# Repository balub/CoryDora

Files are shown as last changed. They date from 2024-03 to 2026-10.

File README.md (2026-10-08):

# CoryDora

A simple open-source, RP2040-based, QMK-compatible 3x3 mechanical macropad.

## Rationale

The main goal of this project is to have a cheap, easy-to-build, feature-rich numpad which is completely open source.

You can now buy the CoryDora yourself at the [Absurd Store](https://shop.absurd.industries/products/cory-dora).
Onboarding instructions are available [here](https://rowan-ninja-baa.notion.site/CoryDora-Onboarding-12d9d3177a9b8016bcddd6904b028f71).
Full build guide is available [here](https://rowan-ninja-baa.notion.site/CoryDora-v1-1-Build-Guide-cc727f8be312492a9d3bb8e5530b1656).

<p align="center">
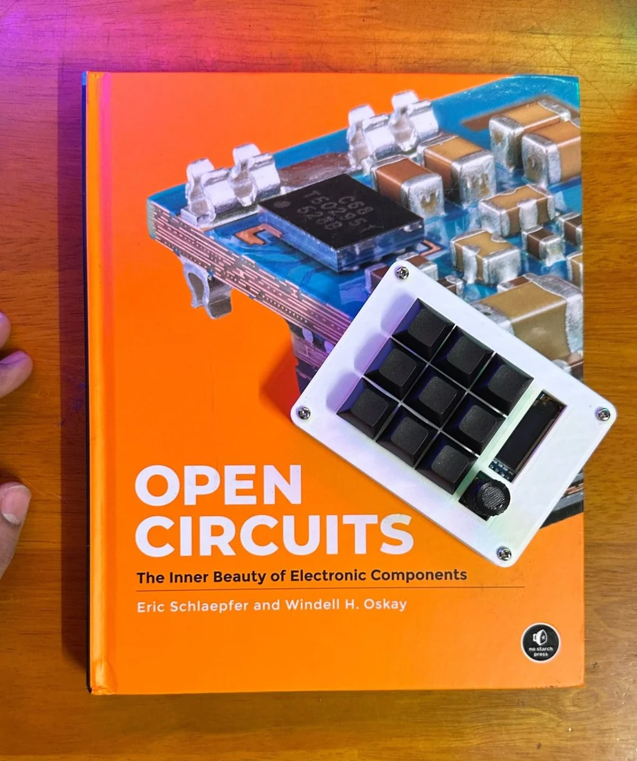
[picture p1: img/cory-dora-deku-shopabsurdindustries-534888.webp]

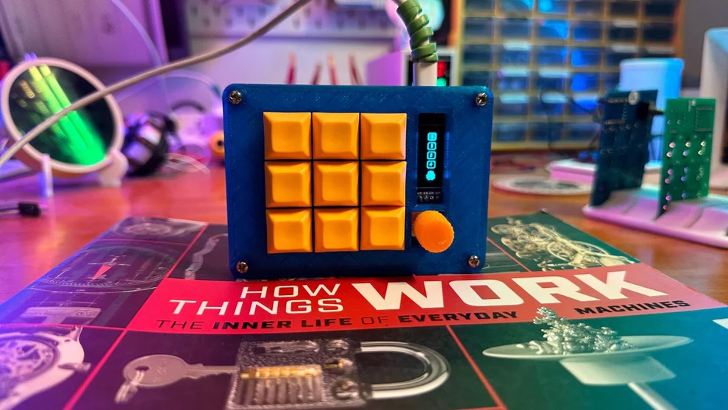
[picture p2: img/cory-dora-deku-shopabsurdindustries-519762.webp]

</p>

## Features:

- Easy to source and build components.
- Hot swappable keys.
- QMK compatible.
- OLED 0.91" screen.
- At least 1 rotary encoder
- Completely open-source.

## Parts list
**Part**|**Quantity**|**Link to buy online**
:-----:|:-----:|:-----:
 Hotswap Sockets|9|https://stackskb.com/store/ttc-pokayoke-hotswap-sockets-v2-10000-cycles
 Through hole 1N4148 Diode|9|https://stackskb.com/store/1n4148-through-hole-diode
 RP2040 zero|1|https://robu.in/product/waveshare-rp2040-zero-without-header
 Rotary Encoders|1|https://robu.in/product/m274-360-degree-rotary-encoder-module-brick-sensor/
 0.91 inch I2C OLED display|1|https://robu.in/product/0-91-inch-128x32-i2c-iic-serial-oled-lcd-display-modulewith-gn
 Mx compatible mechanical switches|9|https://stackskb.com/product-category/switches/linear/

## Firmware

Clone [forked QMK](https://github.com/balub/qmk_firmware) repositories and set up the build environment. See the [build environment setup](https://docs.qmk.fm/#/getting_started_build_tools) and the [make instructions](https://docs.qmk.fm/#/getting_started_make_guide) for more information. Brand new to QMK? Start with our [Complete Newbs Guide](https://docs.qmk.fm/#/newbs).

QMK


## License

Original CoryDora hardware designs and accompanying documentation are licensed
under **CERN-OHL-S-2.0**. You may use, modify, manufacture, and sell the hardware
under its terms. Retain the project attribution and other applicable notices;
provide the complete editable sources under the same licence when required
for distributed derivatives.

See [licensing scope and third-party exclusions](LICENSE) and the
[complete licence text](LICENSES/CERN-OHL-S-2.0.txt). Third-party material retains
its existing licences. The [separate QMK firmware fork](https://github.com/balub/qmk_firmware)
retains its applicable upstream and file-specific licences.

Attribution: **CoryDora project and its contributors**.
Source location: <https://github.com/balub/CoryDora>.

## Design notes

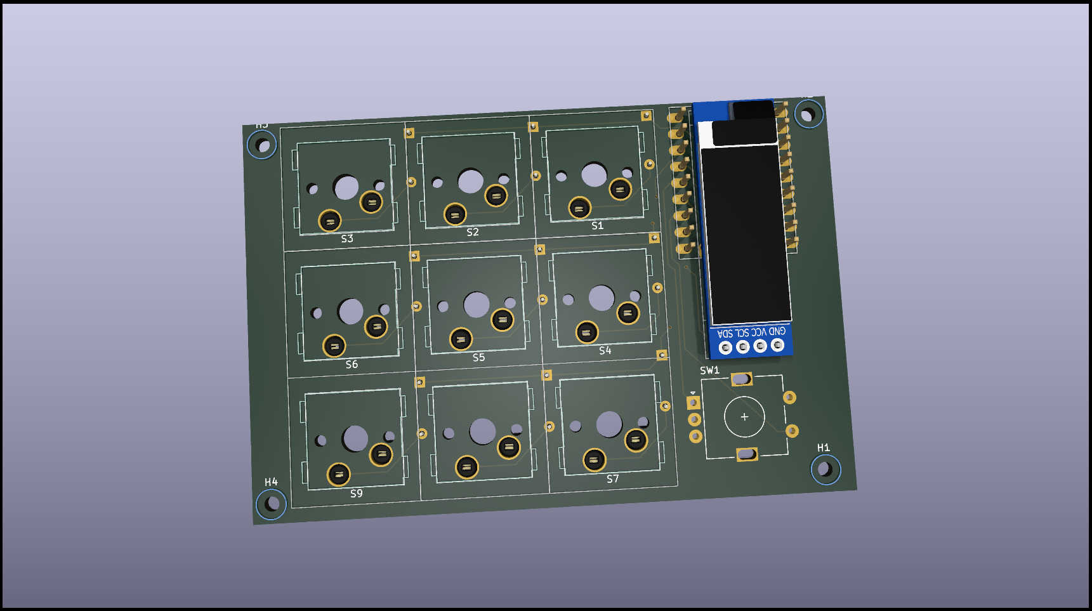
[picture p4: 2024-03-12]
img/CoryDora-front.png

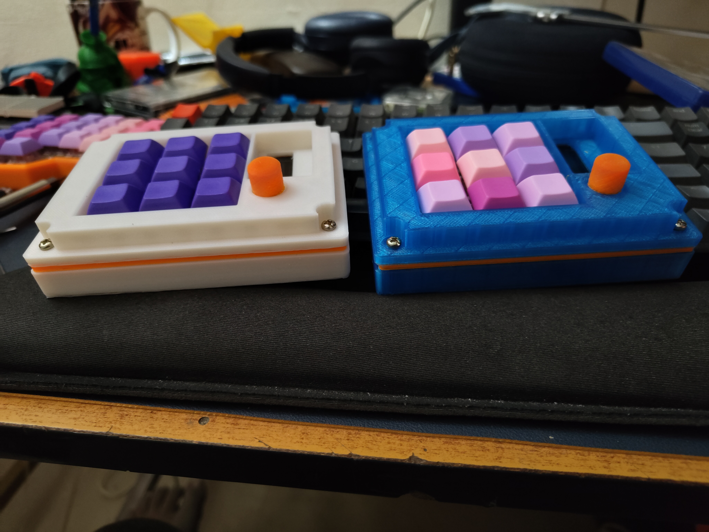
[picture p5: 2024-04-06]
img/CoryDora_Real.jpg

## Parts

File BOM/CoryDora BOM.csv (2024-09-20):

Reference | Value | Datasheet | Footprint | Qty | DNP
D1,D2,D3,D4,D5,D6,D7,D8,D9 | Diode |  | ScottoKeebs_Components:Diode_DO-35 | 9
H1,H2,H3,H4 | MountingHole | ~ | MountingHole:MountingHole_2.2mm_M2 | 4
J1 | OLED_128x32 |  | ScottoKeebs_Components:OLED_128x32 | 1
S1,S2,S3,S4,S5,S6,S7,S8,S9 | Keyswitch | ~ | ScottoKeebs_Hotswap:Hotswap_MX_Plated_1.00u | 9
SW1 | RotaryEncoder_Switch | ~ | Rotary_Encoder:RotaryEncoder_Alps_EC11E-Switch_Vertical_H20mm | 1
U1 | RP2040_Zero |  | ScottoKeebs_MCU:RP2040_Zero | 1

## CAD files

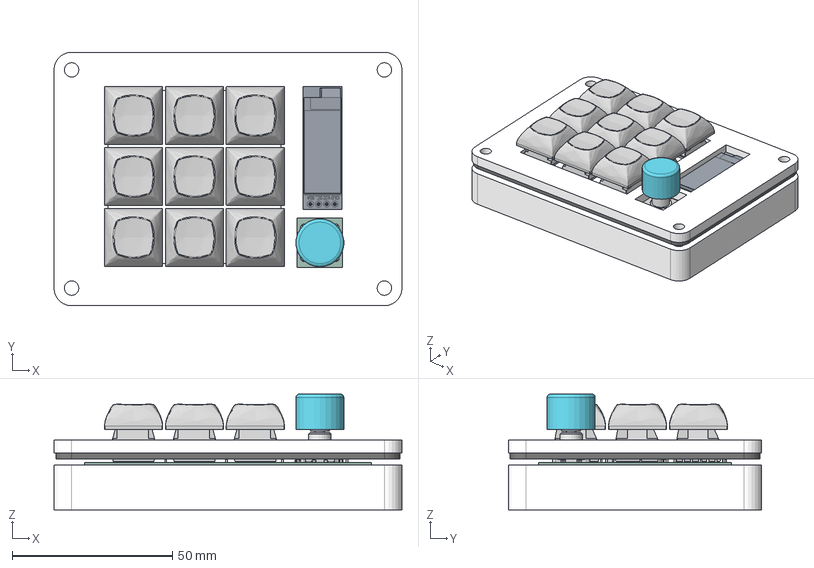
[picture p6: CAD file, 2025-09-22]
Case/v1.2/CoryDora_Fully_Assembled_v1.2.step
108.6 x 79.1 x 36.2 mm
switch v1_9 x 9
EC11
OLED_0.91_128x32
D_DO-35_SOD27_P7.62mm_Horizontal x 9
root
CoryDora_PCB
Case_Bottom
Case_trim
Case_top
Knob
MX Mount v1 x 9

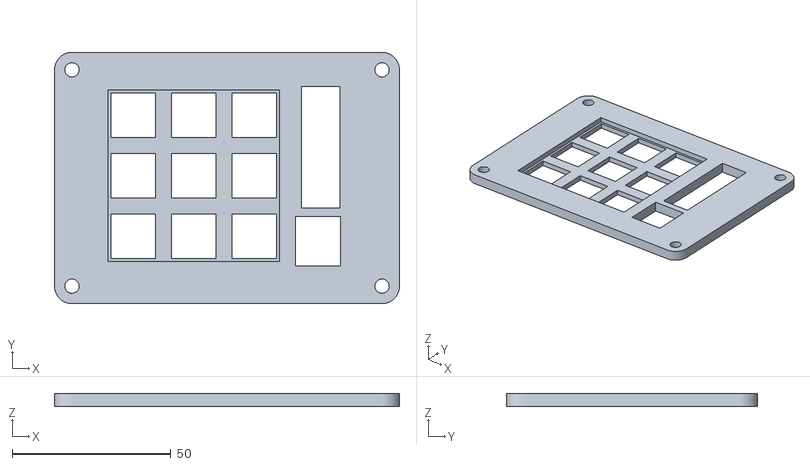
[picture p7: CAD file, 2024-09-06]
Case/v1.2/STLs/Case_top.stl
108.6 x 79.1 x 4.07

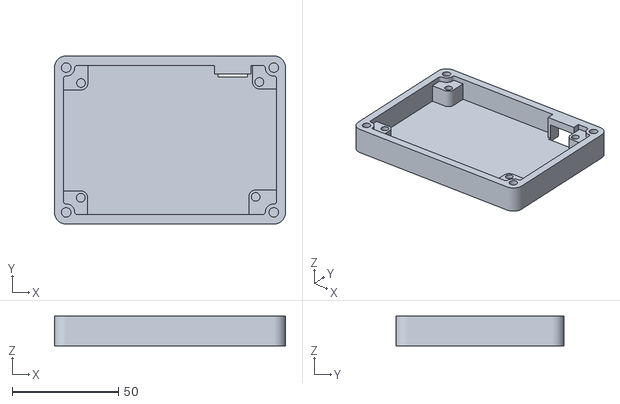
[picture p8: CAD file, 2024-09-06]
Case/v1.2/STLs/Case_Bottom.stl
108.6 x 79.1 x 14.0

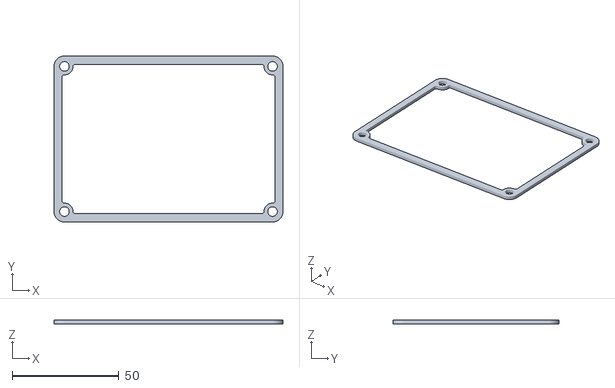
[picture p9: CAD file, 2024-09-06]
Case/v1.2/STLs/Case_trim.stl
107.4 x 77.9 x 1.80

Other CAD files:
Case/v1.2/CoryDora_Fully_Assembled_v1.2.f3z

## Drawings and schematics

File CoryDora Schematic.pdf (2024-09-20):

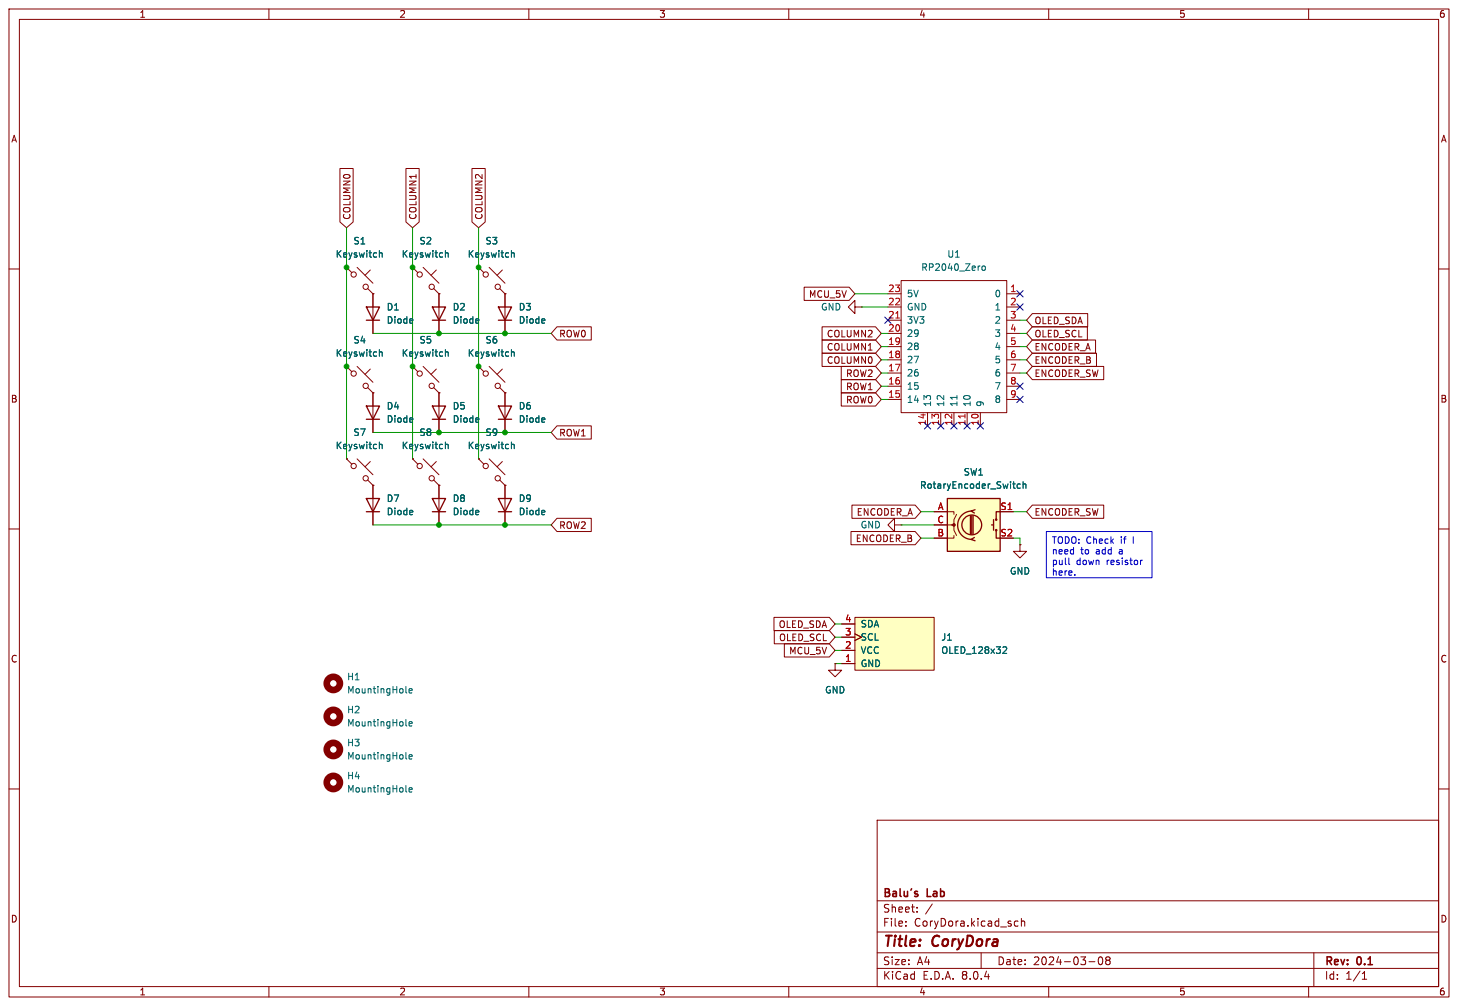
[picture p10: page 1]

TODO: Check if I need to add a

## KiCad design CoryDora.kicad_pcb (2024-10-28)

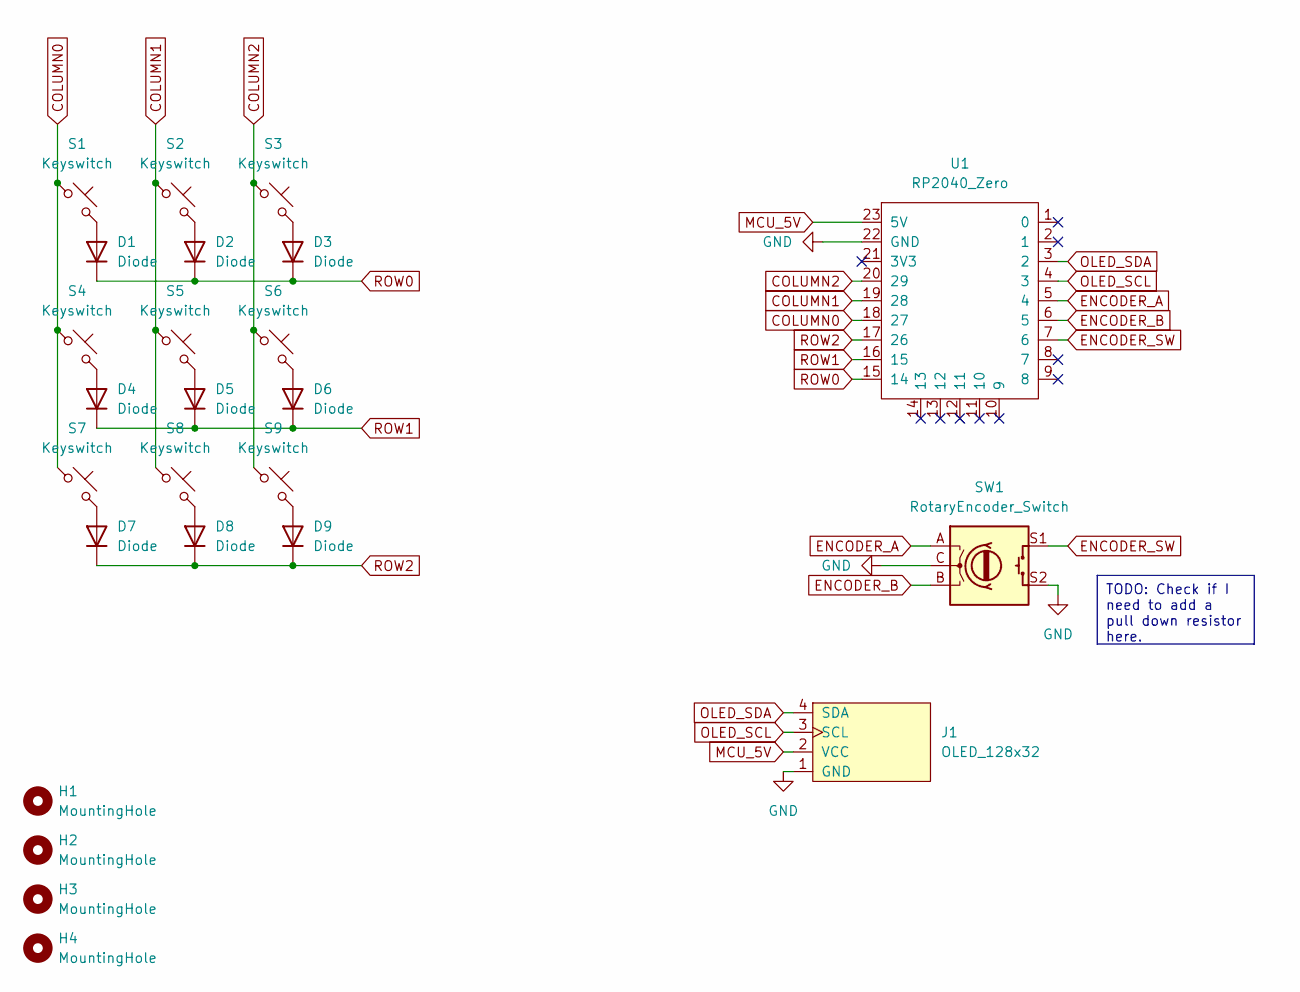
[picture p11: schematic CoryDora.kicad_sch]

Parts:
D1, D2, D3, D4, D5, D6, D7, D8, D9: Diode; Diode_DO-35
H1, H2, H3, H4: MountingHole; MountingHole_2.2mm_M2
J1: OLED_128x32
S1, S2, S3, S4, S5, S6, S7, S8, S9: Keyswitch; Hotswap_MX_Plated_1.00u
SW1: RotaryEncoder_Switch; RotaryEncoder_Alps_EC11E-Switch_Vertical_H20mm
U1: RP2040_Zero

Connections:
COLUMN0: S1.1, S4.1, S7.1, U1.18 (27)
COLUMN1: S2.1, S5.1, S8.1, U1.19 (28)
COLUMN2: S3.1, S6.1, S9.1, U1.20 (29)
ENCODER_A: SW1.A, U1.5 (4)
ENCODER_B: SW1.B, U1.6 (5)
ENCODER_SW: SW1.S1, U1.7 (6)
GND: J1.1 (GND), SW1.C, SW1.S2, U1.22 (GND)
MCU_5V: J1.2 (VCC), U1.23 (5V)
unnamed: D1.2 (A), S1.2
unnamed: D2.2 (A), S2.2
unnamed: D3.2 (A), S3.2
unnamed: D4.2 (A), S4.2
unnamed: D5.2 (A), S5.2
unnamed: D6.2 (A), S6.2
unnamed: D7.2 (A), S7.2
unnamed: D8.2 (A), S8.2
unnamed: D9.2 (A), S9.2
OLED_SCL: J1.3 (SCL), U1.4 (3)
OLED_SDA: J1.4 (SDA), U1.3 (2)
ROW0: D1.1 (K), D2.1 (K), D3.1 (K), U1.15 (14)
ROW1: D4.1 (K), D5.1 (K), D6.1 (K), U1.16 (15)
ROW2: D7.1 (K), D8.1 (K), D9.1 (K), U1.17 (26)

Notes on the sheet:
TODO: Check if I need to add a pull down resistor here.

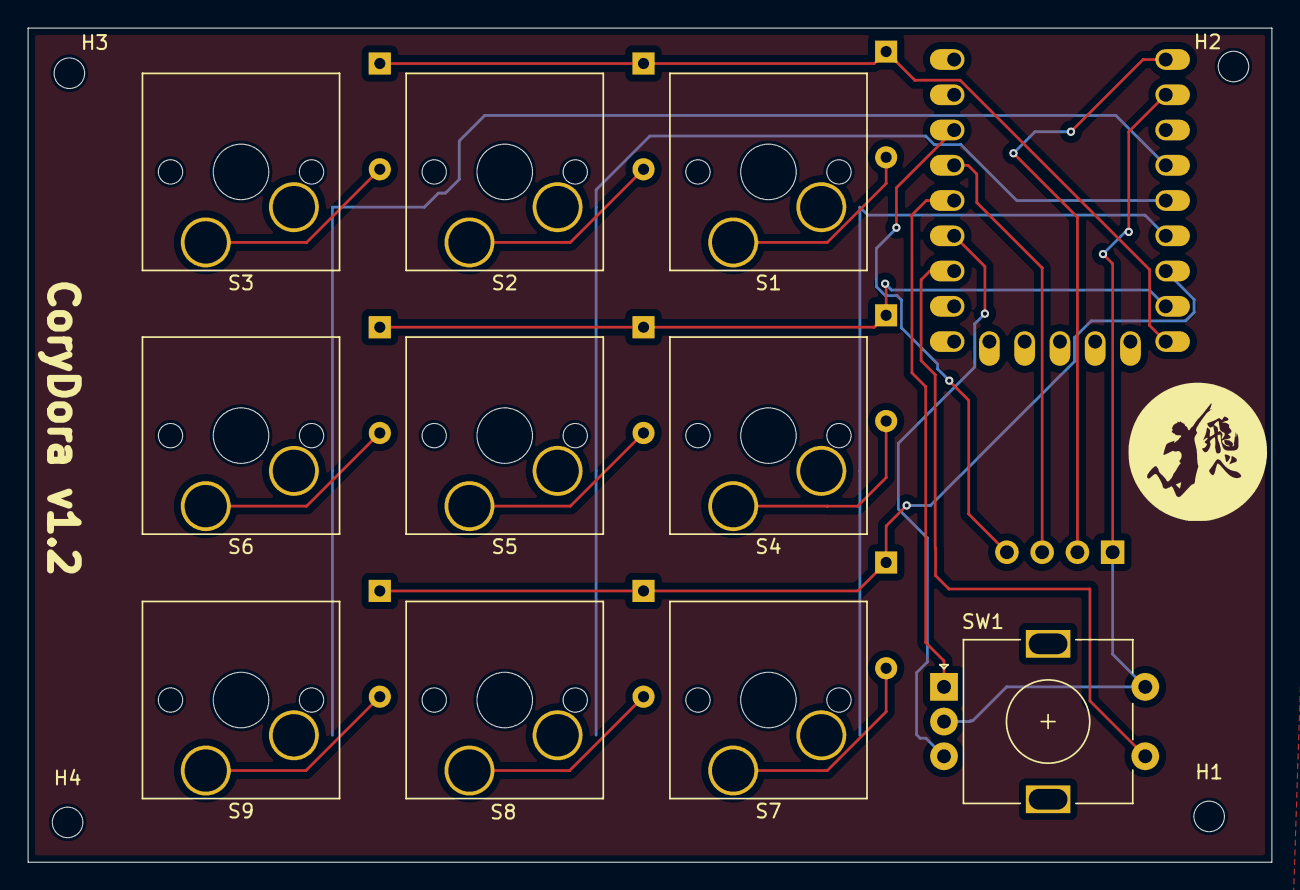
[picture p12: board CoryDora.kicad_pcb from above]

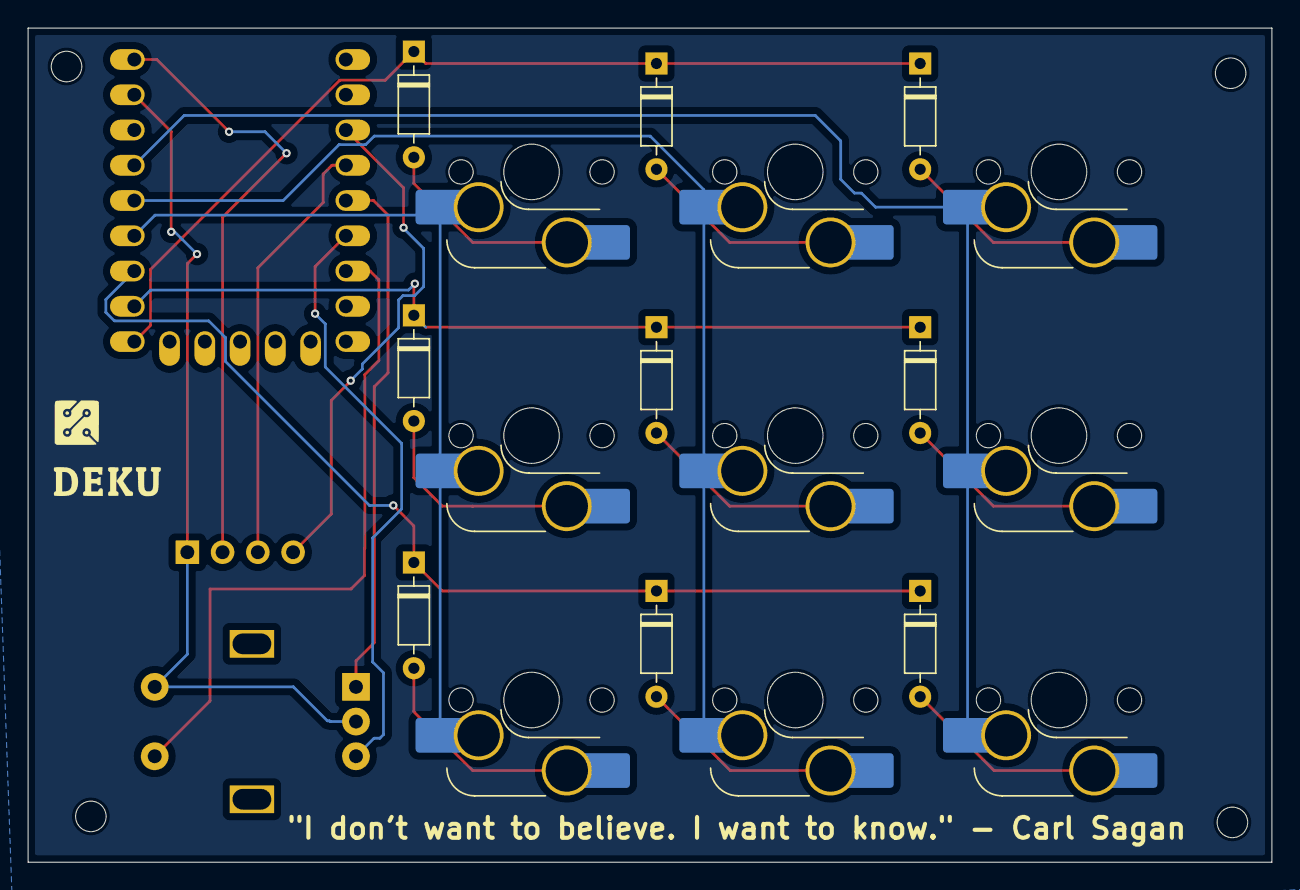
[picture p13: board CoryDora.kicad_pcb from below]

Board: 2 copper layers, 89.6 x 60.1 mm, 25 parts (10 on the bottom side), 22 nets.

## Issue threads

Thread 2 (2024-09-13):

add images to the readme

shreshthmohan, 2024-09-13:
- [ ] exploded view
- [ ] each part's photos (rendered & real maybe)

balub, 2024-09-13:
@shreshthmohan Do you want me to add the image of a raw PCB to the readme ?

shreshthmohan, 2024-09-13:
Yes, I think of every part before assembly too (eventually)

Gives one an idea of how the build will go

shreshthmohan, 2024-10-31:
readme is looking so much better now!

maybe add a link to store saying: "too lazy to build one on your own, [get mine](https://shop.absurd.industries/products/cory-dora)!"

Closed 2024-10-30.

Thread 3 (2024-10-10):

Fixing broken 3D View

shreekumar3d, 2024-10-10:
CoryDora.step looks complete.  However, the 3D view in KiCAD is broken - it doesn't show 3D models when I clone.

Looks like this is due to local references.  In the footprint properties, I see 3D models referenced such as
- ${SCOTTOKEEBS_KICAD}/3dmodels/ScottoKeebs_Hotswap.3dshapes/Hotswap_MX.step
- ${SCOTTOKEEBS_KICAD}/3dmodels/ScottoKeebs_Components.3dshapes/Diode_DO-35.step

Where can I find these source files ?

Two ways to fix this:

1. Provide instructions on where to get the models and how to use them
2. Make them part of the project

balub, 2024-10-15:
Yes @shreekumar3d sir, I intent to add those files as sub-modules to the repo.

shreekumar3d, 2024-10-16:
Sure @balub . Can you say where those models come from ? I will quickly try to pull these in, while you do the sub-modules stuff.

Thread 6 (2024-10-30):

rotary encoder knob gets stuck and is not easy to remove

shreshthmohan, 2024-10-30:
to solve this, i tried to come up with a new design

https://www.thingiverse.com/thing:6813918

@balub please check if this works better (doesn't get stuck)

balub, 2024-10-30:
@shreshthmohan it seems you have saved the model as a draft, could you publish it so that I can download it.

shreshthmohan, 2024-10-30:
Thingiverse prevents me from making things public for 24 hours after creating an account

File linked here too: https://discord.com/channels/1095433416754872392/1281167357871525950/1300227480728375347

shreshthmohan, 2025-09-22:
following up on this.

i added this so that i can realistically remove the encode knob cover to disassemble the case!

can we print this and test with an encode? and close this.

i am not entirely happy with the pattern on this new one (i prefer pattern of the one you printed), but i don't know enough fusion to make it right now.

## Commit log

2024-03-07 feat: base schematic complete
    [CoryDora.kicad_pcb, CoryDora.kicad_sch]
2024-03-07 chore: complete layout in PCB editor
    [CoryDora.kicad_pcb]
2024-03-12 chore: completed PCB design
    [CoryDora.kicad_pcb, CoryDora.kicad_sch]
2024-03-12 chore: removed unimportant texts from silkscreen
    [CoryDora.kicad_pcb]
2024-03-12 chore: added text and graphics to silkscreen
    [CoryDora-B_Cu.gbl, CoryDora-B_Mask.gbs, CoryDora-B_Paste.gbp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]
2024-03-15 chore: added a simple readme for project
    [CoryDora-B_Cu.gbl, CoryDora-B_Mask.gbs, CoryDora-B_Paste.gbp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]
2024-04-05 feat: added case stl and step files
2024-06-11 chore: made modifications for v1.1
    [CoryDora.kicad_pcb]
2024-08-21 chore: added front and bottom copper fill
    [CoryDora-B_Cu.gbl, CoryDora-B_Mask.gbs, CoryDora-B_Paste.gbp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]
2024-09-06 feat: added v1.2 case design
    [Case_Bottom.stl, Case_top.stl, Case_trim.stl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]
2024-09-20 chore: added CoryDora schematic
    [CoryDora BOM.csv]
2024-10-04 chore: added v1.2 case and PCB step files
    [Case_Bottom.stl, Case_top.stl, Case_trim.stl]
2024-10-28 chore: modified readme
    [CoryDora-B_Cu.gbl, CoryDora-B_Mask.gbs, CoryDora-B_Paste.gbp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]
